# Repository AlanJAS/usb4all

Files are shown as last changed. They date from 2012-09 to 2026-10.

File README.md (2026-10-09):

# USB4all

USB4all es una placa para conectar sensores, actuadores y otros dispositivos electrónicos a una computadora mediante USB. Utiliza un **PIC18F4550** y organiza sus funcionalidades en módulos de firmware, con aplicaciones en el **Proyecto Butiá**.

El proyecto Butiá usa la placa USB4all (llamada USB4butia) con motores para crear una plataforma robótica educativa de bajo costo.

[Wiki Proyecto Butiá](https://www.fing.edu.uy/inco/proyectos/butia/mediawiki/index.php?title=Wiki_Buti%C3%A1)

Este repositorio reúne el firmware, el bootloader, diseños de placas, documentación técnica y una herramienta para grabar la aplicación por USB.

## Contenido

| Directorio | Contenido |
| --- | --- |
| [firmware/u4a2](firmware/u4a2/) | Firmware principal y módulos de usuario. |
| [firmware/bootloader](firmware/bootloader/) | Bootloader para instalar y actualizar la aplicación. |
| [fsusb-0.1.11-2](fsusb-0.1.11-2/) | Utilidad de programación USB incluida en el repositorio. |
| [pcb](pcb/) | Diseños de placas, sensores, actuadores y accesorios. |
| [doc](doc/) | Manuales, documentación del proyecto y del microcontrolador. |
| [usb4all_kernel_module](usb4all_kernel_module/) | Código histórico de un módulo para el kernel de Linux. |

## Ramas y herramientas

- **`master`**: desarrollo original, con proyectos para MPLAB C18.
- **[`xc8`](https://github.com/AlanJAS/usb4all/tree/xc8)**: migración a MPLAB XC8, con Makefiles independientes para la aplicación y el bootloader.

**Los comandos de compilación de este README corresponden a la rama `xc8`.** Los módulos opcionales y ejemplos históricos no están necesariamente migrados.

```sh
git clone --branch xc8 https://github.com/AlanJAS/usb4all.git
cd usb4all
```

Si ya tenés el repositorio:

```sh
git fetch origin
git switch xc8
```

## Compilar con XC8

### Requisitos

- GNU Make.
- MPLAB XC8 para PIC; los Makefiles están configurados para **XC8 4.00**.
- Pack **Microchip PIC18Fxxxx_DFP 1.7.171**.
- Python 3.9 o posterior para las comprobaciones de la aplicación.

El compilador y el pack de dispositivos se obtienen por separado:

- [MPLAB XC8](https://www.microchip.com/en-us/tools-resources/develop/mplab-xc-compilers/xc8)
- [Microchip Device Packs](https://packs.download.microchip.com/)

Los Makefiles utilizan estas rutas predeterminadas en Linux:

```text
XC8=/opt/microchip/xc8/v4.00/bin/xc8-cc
DFP=/opt/microchip/mplabx/v6.35/packs/Microchip/PIC18Fxxxx_DFP/1.7.171/xc8
```

`DFP` debe apuntar al subdirectorio `xc8` del pack.

### Aplicación

Desde la raíz del repositorio:

```sh
make -C firmware/u4a2
```

También podés ejecutar `make` directamente dentro de `firmware/u4a2`. El objetivo predeterminado compila y ejecuta las comprobaciones de la imagen.

Archivo para grabar por USB:

```text
firmware/u4a2/build/xc8/usb4all2.hex
```

Para repetir las comprobaciones o limpiar los resultados:

```sh
make -C firmware/u4a2 check
make -C firmware/u4a2 clean
```

### Bootloader

```sh
make -C firmware/bootloader
```

Archivo para grabar con un programador de hardware:

```text
firmware/bootloader/build/xc8/bootloader.hex
```

Para limpiar:

```sh
make -C firmware/bootloader clean
```

### Usar otras rutas

Las variables se pueden sobrescribir en la línea de comandos de cualquiera de los dos Makefiles:

```sh
make -C firmware/u4a2 \
  XC8=/otra/ruta/bin/xc8-cc \
  DFP=/otra/ruta/PIC18Fxxxx_DFP/1.7.171/xc8
```

Si el compilador está en el `PATH`, usá `XC8=xc8-cc`.

### Proyectos MPLAB

Se conservan proyectos de distintas etapas del desarrollo. Para reproducir la compilación descrita aquí, usá los Makefiles de `firmware/u4a2` y `firmware/bootloader`. Los proyectos y scripts de enlace de C18 no deben reutilizarse directamente para enlazar con XC8.

## Grabar la placa

### 1. Instalar el bootloader

Si el PIC no tiene el bootloader, necesitás un programador de hardware compatible, como PICkit.

1. Compilá el bootloader.
2. Conectá el programador según el pinout de tu placa.
3. Seleccioná el PIC18F4550 en el software del programador.
4. Grabá y verificá `firmware/bootloader/build/xc8/bootloader.hex`.

Luego podés cargar la aplicación por USB. **El HEX de la aplicación no incluye el bootloader**: en XC8 comienza en `0x08C0` y se genera sin bits de configuración.

### 2. Compilar fsusb

La utilidad incluida utiliza la API de **libusb 0.1** (`usb.h`, enlace con `-lusb`). Necesitás un compilador C, Make y las cabeceras y biblioteca compatibles con esa API; libusb 1.0 por sí sola no sustituye esta dependencia.

```sh
make -C fsusb-0.1.11-2
```

### 3. Entrar en modo bootloader

Con la placa conectada por USB:

1. Mantené presionado el botón de programación.
2. Pulsá y soltá el botón de reset.
3. Soltá el botón de programación.

Comprobá la identificación con:

```sh
lsusb
```

| Estado | VID:PID |
| --- | --- |
| Aplicación USB4all | `04d8:000c` |
| Bootloader | `04d8:000b` |

### 4. Grabar y ejecutar la aplicación

Desde la raíz del repositorio:

```sh
./fsusb-0.1.11-2/fsusb --program firmware/u4a2/build/xc8/usb4all2.hex
```

La opción `--program` graba y verifica. También podés verificar por separado:

```sh
./fsusb-0.1.11-2/fsusb --verify firmware/u4a2/build/xc8/usb4all2.hex
```

Para salir del bootloader y ejecutar la aplicación:

```sh
./fsusb-0.1.11-2/fsusb --reset
```

Comprobá que la placa vuelva a aparecer como `04d8:000c`.

Si el sistema deniega el acceso USB, revisá los permisos del dispositivo o las reglas udev de tu distribución. Para una operación puntual, podés ejecutar el comando de grabación con `sudo`.

## Arquitectura y módulos

El firmware base gestiona la comunicación USB, los módulos y los recursos compartidos. Cada módulo expone operaciones de inicialización, liberación y configuración, además de procesar sus comandos específicos.

En la rama `xc8`, los módulos activos se enumeran explícitamente en [module_registry.h](https://github.com/AlanJAS/usb4all/blob/xc8/firmware/u4a2/user/module_registry.h). Incluyen administración, detección de módulos, puertos, AX12, botones, motores y módulos de sensores y actuadores Butiá.

Para incorporar un módulo a esta compilación:

1. Implementá su descriptor y callbacks tomando como referencia un módulo activo de `firmware/u4a2/user/`.
2. Agregá sus fuentes y dependencias a `SOURCES` en el Makefile de la aplicación.
3. Declaralo y agregalo al final de `U4A_MODULES`, preservando el orden existente.
4. Compilá, ejecutá las comprobaciones y probá sus comandos en la placa.

Los índices dependen del orden del registro: el software de la computadora debe enumerar los módulos por nombre y no conservar índices de una imagen anterior. Los módulos compilados con C18 no son compatibles binariamente con XC8; hay que recompilar la aplicación.

## Comprobaciones y estado de la migración

La aplicación incluye comprobaciones de tamaños y disposición de estructuras, y un script que revisa el HEX y los símbolos generados: direcciones de la aplicación, vectores y ubicación de buffers USB, entre otros aspectos.

Estas comprobaciones no sustituyen las pruebas con la placa. La documentación de migración señala validaciones pendientes del intercambio USB, margen de pila y latencia bajo carga. Una compilación exitosa no demuestra por sí sola el funcionamiento completo en hardware.

El [documento de migración XC8](https://github.com/AlanJAS/usb4all/blob/xc8/firmware/u4a2/README-XC8.md) contiene detalles técnicos e historial de cambios. Algunas secciones conservan referencias a etapas anteriores, como `Makefile.xc8` o la ausencia de una migración del bootloader; para compilar, seguí los comandos anteriores y los Makefiles de la rama.

## Problemas frecuentes

| Problema | Qué revisar |
| --- | --- |
| No se encuentra `xc8-cc` | Sobrescribir `XC8` con la ruta de instalación. |
| Error al localizar el dispositivo o el pack | Revisar `DFP` y que termine en el subdirectorio `xc8`. |
| Falta `usb.h` o falla el enlace con `-lusb` | Instalar los archivos de desarrollo compatibles con libusb 0.1. |
| fsusb no detecta la placa para grabar | Comprobar el modo bootloader (`04d8:000b`), el cable y los permisos USB. |
| La placa no entra en modo bootloader | Comprobar que tenga instalado el bootloader y repetir la secuencia de botones. |
| La aplicación no arranca | Verificar la grabación, el bootloader, los bits de configuración y la compatibilidad del hardware. |

## Documentación y origen

- [USB4all: arquitectura y guía de uso](https://www.fing.edu.uy/inco/proyectos/butia/mediawiki/index.php?title=Usb4all)
- [Grabación del firmware](https://www.fing.edu.uy/inco/proyectos/butia/mediawiki/index.php?title=Usb4all#4._Grabando_el_Firmware)
- [Documentación incluida en el repositorio](doc/usb4all/)
- [Repositorio original en SourceForge](https://sourceforge.net/projects/usb4all/)

USB4all se originó como un trabajo de grado en Ingeniería en Computación de Aguirre, Fernández y Grossy. Su documentación y su integración con Butiá se publican en el sitio de la Facultad de Ingeniería de la Universidad de la República, Uruguay.

## Licencias

La documentación original presenta USB4all bajo **GNU GPL v2**. El repositorio también contiene componentes de terceros con avisos propios, incluidos fuentes de Microchip. Consultá las cabeceras y los archivos de licencia de cada componente antes de reutilizarlo o redistribuirlo.

La licencia de la utilidad fsusb está incluida en [fsusb-0.1.11-2/COPYING](fsusb-0.1.11-2/COPYING).

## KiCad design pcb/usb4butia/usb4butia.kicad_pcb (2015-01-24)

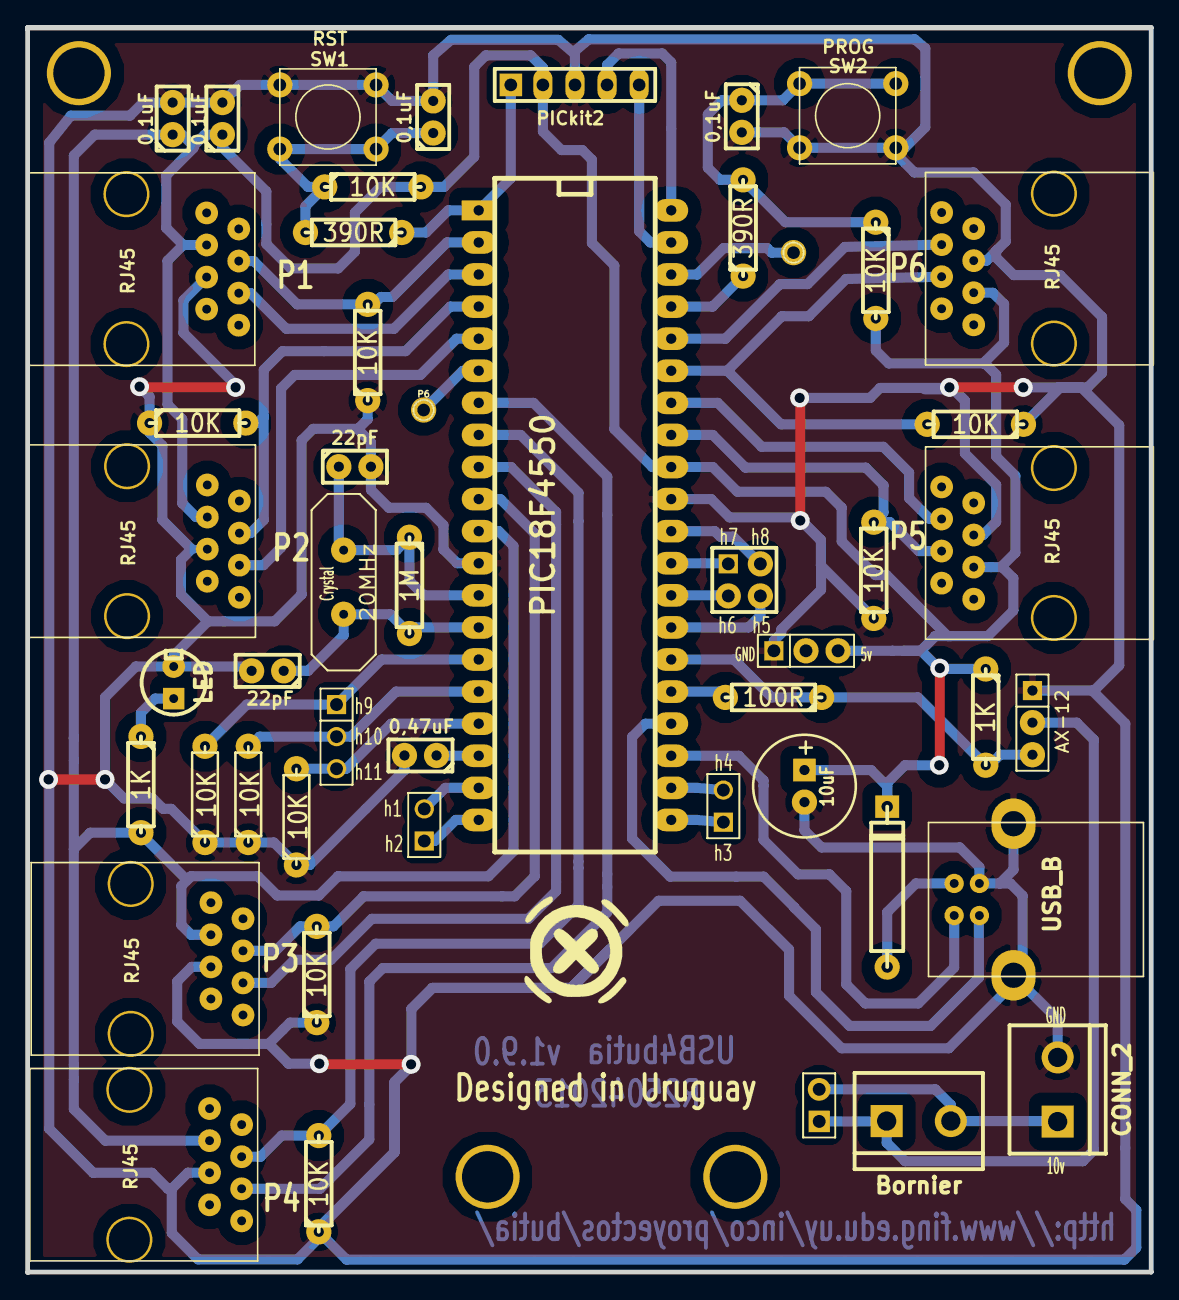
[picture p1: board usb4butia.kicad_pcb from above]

Board: 2 copper layers, 88.9 x 98.5 mm, 50 parts (0 on the bottom side), 44 nets.

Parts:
C1, C2: 22pF; C1
C3, C7, C8, C9: 0,1uF; C1
C4: 0,47uF; C1
C10: 10uF; C1V8
D1: LED; LEDV
D2: 1N5819; D5
J1: USB_B
J2, J3, J4, J5, J6, J7: RJ45; RJ45_8
K1: AX-12; PIN_ARRAY_3X1
K2, K3: CONN_3; PIN_ARRAY_3X1
P1: PICkit2; PIN_ARRAY_5x1
P3, P4, P9: CONN_2; PIN_ARRAY_2X1
P5: CONN_4; PIN_ARRAY_2X2
P6, P7: CONN_1; PINTST
P13: Bornier; bornier2
P14: CONN_2; bornier2
R1, R14: 1K; R3
R2: 1M; R3
R3, R6, R7, R8, R9, R10, R12, R13, R15, R16, R17: 10K; R3
R4, R5: 390R; R3
R11: 100R; R3
SW1: RST; SW_PUSH_SMALL
SW2: PROG; SW_PUSH_SMALL
U1: PIC18F4550; 40DIP-ELL600
X1: 20MHz; HC-18UV

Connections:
AN1: J2.6, U1.3
AN3: J3.6, U1.5
AN4: J7.6, U1.7
AN6: J6.6, U1.9
AN9: J4.6, U1.36
AN10: J5.6, U1.34
D+: J1.3, U1.24
D-: J1.2, U1.23
GND: C1.2, C2.2, C3.2, C4.2, C7.2, C8.2, C9.2, C10.2, D1.2, J1.4, J1.5, J1.6, J2.5, J3.5, J4.5, J5.5, J6.5, J7.5, K1.1, K3.1, P1.3, P14.2, R7.1, R8.1, R9.1, R10.1, R12.1, R13.1, R15.1, R16.1, R17.1, SW1.1, SW2.2, U1.12, U1.31
HK6: P6.1, U1.6
HK15: K2.1, R15.2, U1.15
HK16: K2.2, R16.2, U1.16
HK17: K2.3, R17.2, U1.17
HK19: P4.2, U1.19
HK20: P4.1, U1.20
HK21: P3.1, U1.21
HK22: P3.2, U1.22
HK27: P5.4, U1.27
HK28: P5.3, U1.28
HK29: P5.1, U1.29
HK30: P5.2, U1.30
HK38: P7.1, U1.38
unnamed: C7.1, R5.2, R6.1, SW2.1
unnamed: C3.1, R3.1, R4.2, SW1.2
unnamed: D1.1, R1.1
unnamed: D2.1, J1.1
unnamed: R11.2, U1.25
OSC1: C1.1, R2.1, U1.13, X1.2
OSC2: C2.1, R2.2, U1.14, X1.1
RB4: R5.1, U1.37
RB6: P1.5, U1.39
RB7: P1.4, U1.40
VDC10: K1.2, P9.1, P13.1
VDC10_i: P9.2, P13.2, P14.1
VDD: C8.1, C9.1, C10.1, D2.2, J2.3, J3.3, J4.3, J5.3, J6.3, J7.3, K3.3, P1.2, R1.2, R3.2, R6.2, R14.1, U1.11, U1.32
Vpp: P1.1, R4.1, U1.1
Vusb: C4.1, U1.18
data: K1.3, R11.1, R14.2, U1.26
idAN0: J2.4, R7.2, U1.2
idAN2: J3.4, R8.2, U1.4
idAN5: J7.4, R13.2, U1.8
idAN7: J6.4, R12.2, U1.10
idAN8: J4.4, R9.2, U1.35
idAN12: J5.4, R10.2, U1.33

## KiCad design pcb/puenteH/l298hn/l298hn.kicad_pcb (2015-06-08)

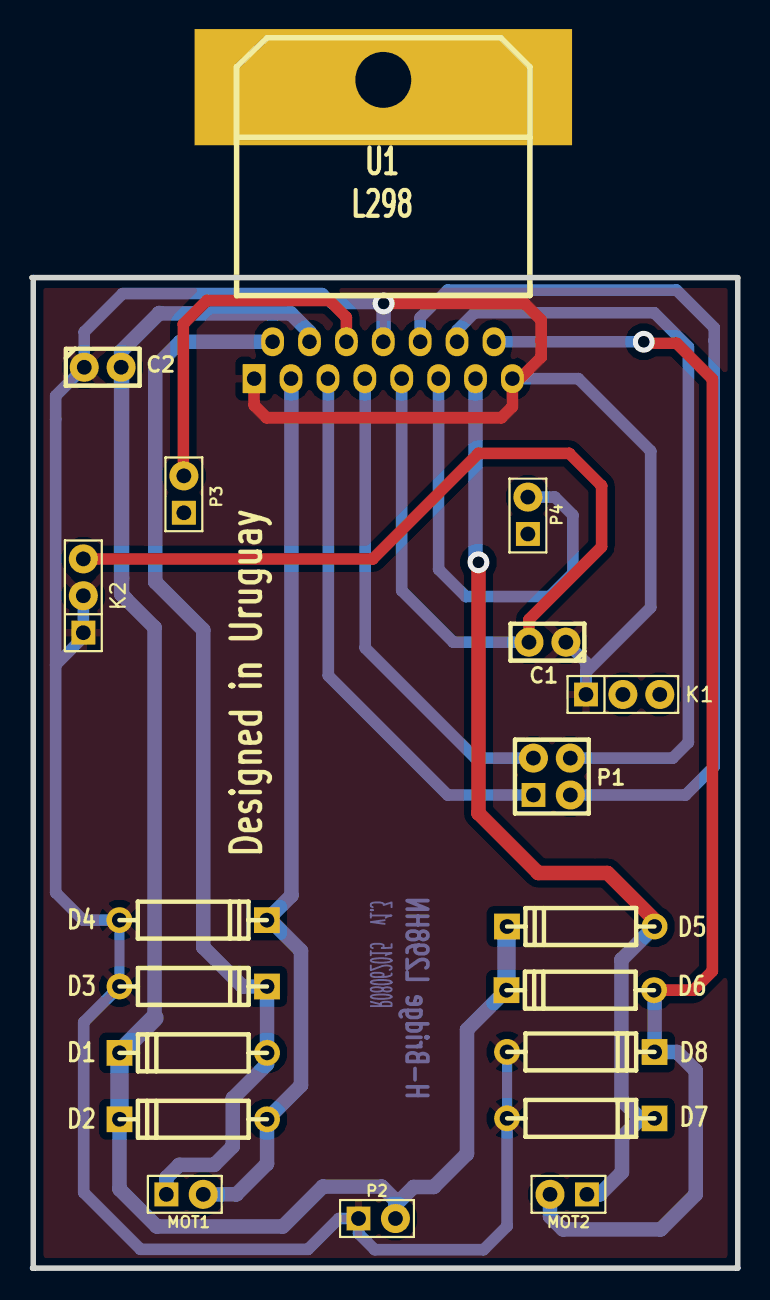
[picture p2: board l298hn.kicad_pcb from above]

Board: 2 copper layers, 48.6 x 68.2 mm, 19 parts (0 on the bottom side), 13 nets.

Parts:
C1, C2: 100nF; C1
D1, D2, D3, D4, D5, D6, D7, D8: DIODE; D4
K1, K2: CONN_3; PIN_ARRAY_3X1
MOT1, MOT2: CONN_2; PIN_ARRAY_2X1
P1: CONN_2X2; PIN_ARRAY_2X2
P2: PWR; PIN_ARRAY_2X1
P3, P4: CONN_2; PIN_ARRAY_2X1
U1: L298; L298HN

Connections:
EnA: P3.2, U1.6
EnB: P4.2, U1.11
GND: C1.1, C2.1, D3.1, D4.1, D7.1, D8.1, K1.1, K2.1, K2.2, P2.1, U1.1, U1.8, U1.15
HK17: C1.2, K1.3, K2.3, U1.9
IN1: P1.1, U1.5
IN2: P1.2, U1.7
IN3: P1.3, U1.10
IN4: P1.4, U1.12
OUT1: D1.1, D3.2, MOT1.1, U1.2
OUT2: D2.1, D4.2, MOT1.2, U1.3
OUT3: D5.1, D7.2, MOT2.1, U1.13
OUT4: D6.1, D8.2, MOT2.2, U1.14
Vcc_12: C2.2, D1.2, D2.2, D5.2, D6.2, P2.2, U1.4

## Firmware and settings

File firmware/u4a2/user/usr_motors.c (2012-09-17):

/* Author                                                   Date        Comment
 *John Pereira                                              28/02/2012
 * Andres Aguirre                                           02/03/2012
 *****************************************************************************/

/** I N C L U D E S **********************************************************/
#include <p18cxxx.h>
#include <usart.h>
#include <delays.h>
#include "system/typedefs.h"
#include "system/usb/usb.h"
#include "user/usr_motors.h"
#include "io_cfg.h"              // I/O pin mapping
#include "user/handlerManager.h"
#include "dynamicPolling.h"
#include "usb4all/proxys/T0Service.h"

/** V A R I A B L E S ********************************************************/
#pragma udata

byte  usrMotorsHandler;     // Handler number asigned to the module
byte* sendBufferUsrMotors; // buffer to send data

#define FIRST_ON    0x01
#define DELAY       0x02
#define SECOND_ON   0x03
#define END         0x04

#define TIME_UNIT        2000
#define LONG_TIME_UNIT   5000
#define LEFT_MOTOR_1   0x01
#define LEFT_MOTOR_2   0x03
#define RIGHT_MOTOR_1  0x02
#define RIGHT_MOTOR_2  0x04

/** P R I V A T E  P R O T O T Y P E S ***************************************/
void UserMotorsProcessIO(void);
void UserMotorsInit(byte i);
void UserMotorsReceived(byte*, byte);
void UserMotorsRelease(byte i);
void UserMotorsConfigure(void);

// Table used by the framework to get a fixed reference point to the user module functions defined by the framework
/** USER MODULE REFERENCE*****************************************************/
#pragma romdata user
const uTab userMotorsModuleTable = {&UserMotorsInit,&UserMotorsRelease,&UserMotorsConfigure,"motors"}; //modName must be less or equal 8 characters
#pragma code

/** D E C L A R A T I O N S **************************************************/
#pragma code module

/* Structure to hold motors */
typedef struct _MOTOR{
    int id;
    int inverse;
} MOTOR;

typedef struct _WHEELS{
    MOTOR left;
    MOTOR right;
} WHEELS;

/* robot wheels */
WHEELS wheels;

void stopRight(){
    writeInfo (wheels.right.id, 32, 0);
}
void backwardRight(){
    endlessTurn(wheels.right.id, -600, 1 );
    registerT0eventInEvent(LONG_TIME_UNIT, &stopRight);
}
void forwardRight(){
    endlessTurn(wheels.right.id, 600, 1);
    registerT0eventInEvent(LONG_TIME_UNIT, &backwardRight);
}
void stopLeft(){
    writeInfo (wheels.left.id, 32, 0);
    registerT0eventInEvent(LONG_TIME_UNIT, &forwardRight);
}
void backwardLeft(){
    endlessTurn(wheels.left.id, -600, 1);
    registerT0eventInEvent(LONG_TIME_UNIT, &stopLeft);
}
void forwardLeft(){
    endlessTurn(wheels.left.id, 600, 1);
    registerT0eventInEvent(LONG_TIME_UNIT, &backwardLeft);
}

void sexyMotorMoveStart(){
    setEndlessTurnMode(wheels.left.id, 1);
    setEndlessTurnMode(wheels.right.id, 1);
    registerT0event(TIME_UNIT, &forwardLeft);
}

/* 
 * Function to auto-detect motors (robot wheels)
 * the less id motor correspond to left wheel
 * the other one to right wheel.
 */
void autoDetectWheels() {
    byte num_motors = 2;
    byte index = 0;
    byte list_motors[2];
    int _id, _error, _data;
    byte i=0;
    for (i ; i<255; i++){
        ax12SendPacket (i, 0, PING, 0);
        ax12ReadPacket (&_id, &_error, &_data);
        if (_id==i) {
            list_motors[index] = i;
            index++;
            if (index==num_motors) {
                //Set found motors as Rigth/Left wheels
                wheels.left.id = list_motors[0];
                wheels.left.inverse = 0;
                wheels.right.id = list_motors[1];
                wheels.right.inverse = 1;
                sexyMotorMoveStart();
                break;
            }
        }
    }
}

/******************************************************************************
 * Function:        UseBuzzerInit(void)
 *
 * PreCondition:    None
 *
 * Input:           None
 *
 * Output:          None
 *
 * Side Effects:    None
 *
 * Overview:        This function is initialices the resources that the user module needs to work, it is called by the framework
 *                    when the module is opened
 *
 * Note:            None
 *****************************************************************************/
void UserMotorsInit(byte i) {
    usrMotorsHandler = i;
    // add my receive function to the handler module, to be called automatically when the pc sends data to the user module
    setHandlerReceiveFunction(usrMotorsHandler,&UserMotorsReceived);
    // add my receive pooling function to the dynamic pooling module, to be called periodically
    /* andres res = addPollingFunction(&UserMotorsProcessIO);*/
    // initialize the send buffer, used to send data to the PC
    sendBufferUsrMotors = getSharedBuffer(usrMotorsHandler);
}

/******************************************************************************
/* Function:        UserAX12Configure(void)
 *
 * PreCondition:    None
 *
 * Input:           None
 *
 * Output:          None
 *
 * Side Effects:    None
 *
 * Overview:        This function sets the specific configuration for the user module, it is called by the framework
 *
 *
 * Note:            None
 *****************************************************************************/
void UserMotorsConfigure(void){
// Do the configuration
}

/******************************************************************************
 * Function:        UserAX12ProcessIO(void)
 *
 * PreCondition:    None
 *
 * Input:           None
 *
 * Output:          None
 *
 * Side Effects:    None
 *
 * Overview:        This function is registered in the dinamic polling, who call ir periodically to process the IO interaction
 *                    int the PIC, also it can comunicate things to the pc by the USB
 *
 * Note:            None
 *****************************************************************************/

void UserMotorsProcessIO(void){
    if((usb_device_state < CONFIGURED_STATE)||(UCONbits.SUSPND==1)) return;
}//end ProcessIO

/******************************************************************************
 * Function:        UserAX12Release(byte i)
 *
 * PreCondition:    None
 *
 * Input:           None
 *
 * Output:          None
 *
 * Side Effects:    None
 *
 * Overview:        This function release all the resources that the user module used, it is called by the framework
 *                    when the module is close
 *
 * Note:            None
 *****************************************************************************/

void UserMotorsRelease(byte i) {
    unsetHandlerReceiveBuffer(i);
    unsetHandlerReceiveFunction(i);
    //unregisterT0event(&MotorsEvent);
    //removePoolingFunction(&UserMotorsProcessIO);
}
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

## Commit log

2012-07-24 move a 4 wheels butiá
2012-08-10 fixed problem with compiler and shifing bits, more info see http://www.microchip.com/forums/m135395.aspx
    [ax12.c]
2012-08-10 fixed turning led on @ init, sorry aylen for the bug injection :P and added a temp function for getPosition
2012-12-05 added copper logo
    [usb4butia.brd]
2012-12-14 Add AllSensors for order + key chain
    [$logo-append.brd, llavero.brd, logo.brd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]
2013-12-12 add led, not finish yet
    [boton_Plantilla.brd, led.sch]
2013-12-12 distance module sensor v1.9.1
    [sharp.brd, sharp.sch]
2013-12-12 distance module sensor v2.0
    [sharp.brd]
2013-12-13 update plantilla_allsen with the new distance module
    [plantilla_allsenAdvance.brd]
2014-01-31 module grey taked away from module ligth
    [ldr.brd, luz.brd, luz.sch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]
2014-08-07 Fix capacitor problem v1.2
    [l298hn.kicad_pcb]
2015-01-23 Generic sensor working
    [generico.brd, generico.sch]
2015-01-24 Usb4butia 1.9 with logo
    [usb4butia.brd, usb4butia.kicad_pcb]
2015-06-08 shield v1.3
    [l298hn.brd, l298hn.kicad_pcb]
2015-06-11 fix hk17 link
    [l298hn.brd, plantilla_allsenV2.kicad_pcb]
